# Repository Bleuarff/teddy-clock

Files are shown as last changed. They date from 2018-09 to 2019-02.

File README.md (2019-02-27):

# Teddy-clock

An alarm clock that does not display the time, but lights itself depending on the time of the day.

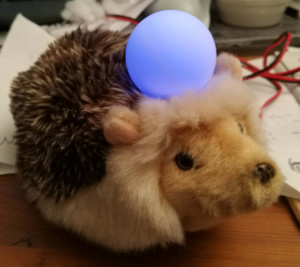
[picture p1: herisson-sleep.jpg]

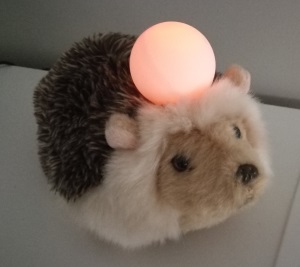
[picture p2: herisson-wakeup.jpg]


## Overview

An esp8266 microcontroller lights an RGB led in different colors depending whether the children must stay in their room or they are allowed to wake their parents up.  
A full-on led in the dead of the night is a sure way for kids to not go back to sleep if they ever wake up. To avoid this, a photoresistor is used to sense ambient light and adjust luminosity accordingly.  
The setup uses an RTC clock with backup battery to help keep time reliably. Daylight saving is taken into account.

The clock uses 3 parameters:
- sleep time: time at which children must go to bed. Led becomes blue,
- wake-up times: times at which children may leve their room at wake their parents up. One for week days, and another one for weekends (one can dream of a Sunday sleep in). Led goes orange for 2 hours.

To update these times, the clock offers a web interface. It's not connected to home wifi for various reasons but instead creates its own SSID when you need it.

## Schema

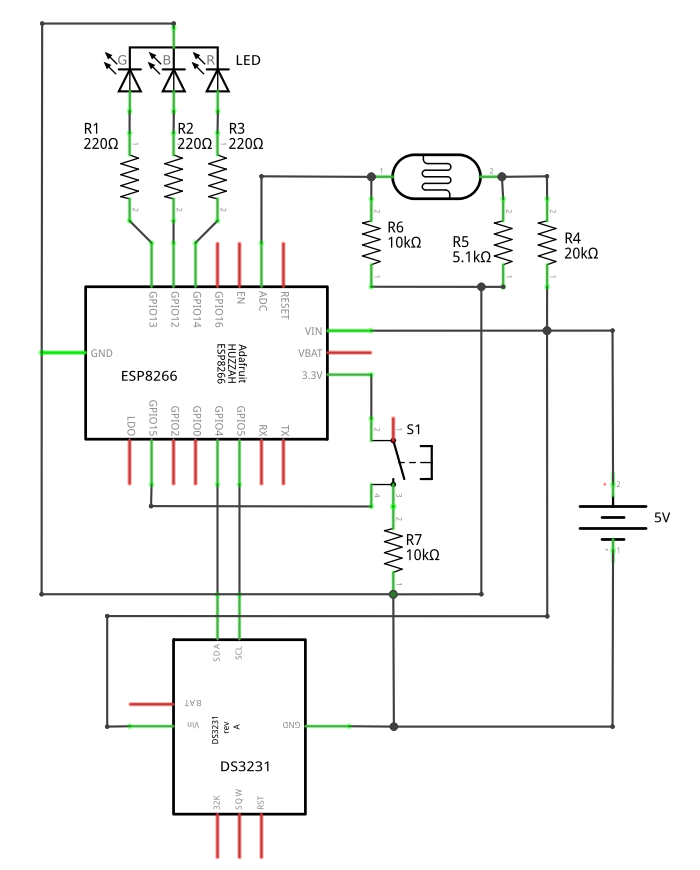
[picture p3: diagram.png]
schema


## Wifi

When you press the button, the clock creates its own SSID. You must connect to network **Hérisson** (public, no authentication). Ease of use trumps everything in such a simple, low-risk project. SSL and auth (WPA2-PSK) are not worth the hassle, both for dev and use. Wifi is off most of the time anyway.  
Go to **http://192.168.14.1** to access the web interface. There, you can edit any of the times (sleep time, wake-up times for weekdays and weekends) as well as the current time and date. Web ui is a single html file uploaded to esp8266's internal file system (SPIFFS).  
The led blinks green when wifi is on. Just press the button again to switch it off.

Why not having it connected permanently?
- home wifi is flaky in the room,
- very sporadic usage does not need 100% connection,
- lower power usage when modem is off

## EEPROM Layout

esp8266 has 4k EEPROM. We use it to store the alarms (4 bytes each) and daylight saving flag (1 if winter time has been done, LSB bit in first byte of the memory bank). Alarm times are stored in minutes since 00:00.

````
Address |  value   | Desc  
--------|----------|------
00h     | 00000001 | winter time change done  
01h-04h |          | sleep time  
05h-08h |          | weekdays wakeup time  
09h-12h |          | weekend wakeup time
````

## Conventions

- Day of week (dow): 1: Monday, 2: Tuesday, (...), 7: Sunday

## Calibration

Light output is proportional to ambiant light. The relation is not the simple identity function f(x) = x.
To create the ideal function, we want to plot values.
The sketch `calibrage` creates a web server (public SSID Hérisson, 192.168.14.1) with endpoints:  
- `GET /sense` to retrieve ambiant light value (theoretically 0-1024),  
- `POST /led?r=R&g=G&b=B` to set led output ; R, G and B being the PWM values for each channel.

We try to find the ideal output in each color (sleep blue and wakeup orange) for multiple ambiant light values. Results are in `resultats_calibrage.ods` file.  
For each channel, we want to write a function that more or less reflects the calibration data points. The ideal function should be superimposed over the data points if plotted along them. We do that by considering that the values between 2 data points should observe an affine function (with data range extremities being minimum & maximum values).  
`tests/pwm_function/pwm_function.cpp` implements the affine functions and compares with calibration data to verify that's ok ; and `herisson/lightModulator.ino` simply copies this code, with a few last-minute adjustments.

## Misc

- DS3231 handles leap years correctly.
- Daylight saving time change is checked and performed on sunday in the last 7 days of march and october. Update time and set winter time flag in eeprom.
- To upload a sketch onto the ESP8266, it must in bootload mode. The procedure is as follow:

    1. Hold down the GPIO0 button, the red LED will be lit
    2. While holding down GPIO0, click the RESET button
    3. Release RESET, then release GPIO0
    4. When you release the RESET button, the red LED will be lit dimly, this means it's ready to bootload

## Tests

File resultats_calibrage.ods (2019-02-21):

Lumière ambiante | Bleu | Red (orange) | Green (orange) | Blue func affine |  | Red affine |  | Green affine
 |  |  |  | coef | y at origin | coef | y at origin | coef | y at origin
0 | 40 | 40 | 80
7 | 40 | 40 | 80
15 | 80
20 | 100 | 70 | 140 |  |  | 2,3076923077 | 23,8461538462 | 4,6153846154 | 47,6923076923
65 | 100 | 100 | 200 |  |  | 0,6666666667 | 56,6666666667 | 1,3333333333 | 113,3333333333
165 | 280 | 200 | 400 | 1,8 | -17 | 1 | 35 | 2 | 70
268 | 400 | 250 | 500 | 1,1650485437 | 87,7669902913 | 0,4854368932 | 119,9029126214 | 0,9708737864 | 239,8058252427
350 | 600 | 350 | 700 | 2,4390243902 | -253,6585365854 | 1,2195121951 | -76,8292682927 | 2,4390243902 | -153,6585365854
416 | 700 | 350 | 700 | 1,5151515152 | 69,696969697 | 0 | 350 | 0 | 700
508 | 800 | 400 | 800 | 1,0869565217 | 247,8260869565 | 0,5434782609 | 123,9130434783 | 1,0869565217 | 247,8260869565
590 | 1000 | 400 | 800 | 2,4390243902 | -439,0243902439 | 0 | 400 | 0 | 800
605 | 1000
700 | 1000 | 500 | 1000 |  |  | 0,9090909091 | -136,3636363636 | 1,8181818182 | -272,7272727273
774 | 1024 | 1024 | 1024 |  |  | 7,0810810811 | -4456,7567567568 | 0,3243243243 | 772,972972973

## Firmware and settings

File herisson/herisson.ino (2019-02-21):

#include <Wire.h>
#include <EEPROM.h>
#include "FS.h"
#include <ESP8266WebServer.h>

const uint8_t RTC_ADDRESS = 0x68; // i2C address of the DS3231

// All possible states for the led
enum LedStates {Dodo, Debout, Off};

const byte redPin = 14;
const byte greenPin = 13;
const byte bluePin = 12;
const byte switchPin = 15;
const int CLOCK_CHECK_INTERVAL = 5000; // time between clock checks

// Object to store timestamp
// seconds are not needed.
struct Time {
  byte hour;
  byte min;
  byte date;
  byte month;
  byte dow;
  byte year;
};

// Store light modulation factor for each rgb channel
// struct ModFactor {
//   float rf; // red channel
//   float gf; // green channel
//   float bf; // blue channel
// };

// 3 alarms needed
int dodo, wakeup1, wakeup2;
bool winterTimeChangeDone;

// timestamp of last time we checked time & set led according to it
unsigned long lastClockCheck;

// server object
ESP8266WebServer server(80);

void setup(){
  Serial.begin(115200);
  Wire.begin();

  pinMode(redPin, OUTPUT);
  pinMode(bluePin, OUTPUT);
  pinMode(greenPin, OUTPUT);
  pinMode(switchPin, INPUT);

  setAirplaneMode();

  // for dev/tests: set RTC
  // setTime((Time){19, 59, 8, 10, 1, 18});

  EEPROM.begin(13); // 13 bytes needed. cf readme for usage/Layout

  winterTimeChangeDone = (EEPROM.read(0) & 0b00000001) == 1;
  Serial.print("Winter time change done: ");
  Serial.println(winterTimeChangeDone ? "oui": "non");

  // get all alarms stored in EEPROM
  EEPROM.get(1, dodo);
  EEPROM.get(5, wakeup1);
  EEPROM.get(9, wakeup2);

  Serial.print("Dodo time: ");
  printAlarm(dodo);
  Serial.print("Lever (semaine): ");
  printAlarm(wakeup1);
  Serial.print("Lever (weekend): ");
  printAlarm(wakeup2);

  if (!SPIFFS.begin()){
    Serial.println("SPIFFS mount fail.");
  }

  lastClockCheck = millis();
}

void loop(){
  static unsigned long lastWifiSwitch = 0;
  static bool isUpdateMode = false; // true when switch is pressed, until next press
  static bool serverOK = false;

  int switchState = digitalRead(switchPin);

  // act upon switch pressed if not too close from last press. Avoids 1 press to be detected multiple times (a kind of debounce)
  if (switchState == HIGH && millis() - lastWifiSwitch >= 3000){
    isUpdateMode = !isUpdateMode;

    if (isUpdateMode){
      // start wifi & server
      serverOK = startServer();
    }
    else{
      // switch off wifi
      bool res = stopServer();
      // led red if error
      if (!res){
        digitalWrite(redPin, HIGH);
        digitalWrite(greenPin, LOW);
        digitalWrite(bluePin, LOW);
        delay(5000);
      }
    }

    lastWifiSwitch = millis(); // debounce: keep track of last time we registered a switch between clock check and update mode
  }

  // in update mode, blink green if wifi & server are set up ok. Otherwise show red
  if (isUpdateMode){
    server.handleClient();
    if (serverOK)
      blink(1);
    else{
      digitalWrite(redPin, HIGH);
      digitalWrite(greenPin, LOW);
      digitalWrite(bluePin, LOW);
    }
  }

  // check time & set led if update mode, (i.e. server) is inactive.
  // also use millis & time compare instead of delay, for non-blocking code
  if (!isUpdateMode && millis() - lastClockCheck >= CLOCK_CHECK_INTERVAL){
    Time t = getTime(); // read time. Already adjusted for daylight savings

    if (t.month == 0){ // in case of error, getTime returns a Time with all members set to 0
      Serial.print("invalid time\n");
      lastClockCheck = millis();
      return;
    }

    printTime(t);

    // gets clock  state to apply
    const LedStates lightState = getLightState(t);
    printState(lightState);

    setLed(lightState); // update led state

    lastClockCheck = millis();
  }
}

// Write RGB values from clockstate
// state: clock state
void setLed(LedStates state){
  int red, green, blue; // pwm value for each pin
  const int lightLvl = analogRead(A0); // ambiant light level

  switch(state){
    case Off:
      red = green = blue = 0;
      break;
    case Dodo:
      red = green = 0;
      blue = (int)computeBlueChannel(lightLvl);
      break;
    case Debout:
      blue = 0;
      green = (int)computeGreenChannel(lightLvl);
      red = (int)computeRedChannel(lightLvl);
      break;
  }
  analogWrite(redPin, red);
  analogWrite(greenPin, green);
  analogWrite(bluePin, blue);

  Serial.printf("A %i\tR %i\tG %i\tB %i\n", lightLvl, red, green, blue);
}

// return the state to apply to the led based on current time & global alarms
// alarms are assumed to be ordered: wakeup1 < wakeup2 < off < dodo
LedStates getLightState(Time t){
  int ts = t.hour * 60 + t.min; // convert time struct into a single number, number of minutes since 00:00
  int wakeup = t.dow <= 5 ? wakeup1 : wakeup2; // sets which wakeup time to use, week or weekend
  int offTime = wakeup + 120; // switch light off 2 hours after wakeup time

  if (ts < wakeup)
    return Dodo;
  else if (ts < offTime)
    return Debout;
  else if (ts < dodo)
    return Off;

  return Dodo;
}

// set modulation factor from light sensor
// Currently: linear relationship between ambiant light value and output led value, for all color channels
// TODO: calibrate: min/max value for min/max ambiant light values. See calibrage_photores sketch
// ModFactor getModFactor(){
//   int lightLvl = analogRead(A0);
//   float lightRatio = (float)lightLvl / 1024;
//   return { lightRatio, lightRatio, lightRatio };
// }

// displays alarm
void printAlarm(int a){
  byte hr = a / 60;
  byte min = a % 60;
  Serial.printf("%i:%i\n", hr, min);
}

void printTime(Time t){
  Serial.print(t.hour);
  Serial.print(":");
  Serial.print(t.min);
  Serial.print(" ");
  Serial.print(t.date);
  Serial.print("/");
  Serial.print(t.month);
  Serial.print(" ");
  Serial.print(t.dow);
  Serial.printf(" 20%i\n", t.year);
}

void printState(LedStates l){
  Serial.print("Apply: ");
  switch (l){
    case Dodo:
      Serial.print("dodo\n");
      break;
    case Debout:
      Serial.print("debout\n");
      break;
    case Off:
      Serial.print("off\n");
      break;
  }
}

// color: specify which color to set when blinking:
// 0: red
// 1: green
// 2: blue
void blink(byte color){
  static unsigned long lastBlink = millis();
  static bool blinkOn = false;

  if (millis() - lastBlink >= 800){
    blinkOn = !blinkOn;

    if (blinkOn){

      digitalWrite(redPin, color == 0 ? HIGH : LOW);
      digitalWrite(greenPin, color == 1 ? HIGH : LOW);
      digitalWrite(bluePin, color == 2 ? HIGH : LOW);
    }
    else{
      digitalWrite(redPin, LOW);
      digitalWrite(greenPin, LOW);
      digitalWrite(bluePin, LOW);
    }

    lastBlink = millis();
  }
}

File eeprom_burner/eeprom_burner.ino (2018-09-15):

// Send file data, write each byte to eeprom, starting at offset 2.
// when file complete, get length and write to eeprom at offset 0. Then proceeds to read the content and send it back

// uses an RGB led for debugging. Blue: arduino started. Red: message incoming. Green: message finished

#include <Wire.h>
#define EEPROM_ADDRESS 0x50 // i2C address of the 24LC256 eeprom
#define BUFFER_SIZE 30 // Wire internal buffer is 32 bytes, of which 2 are for the address
#define PAGE_SIZE 64 // EEPROM page size

unsigned int numReceived = 0; // counter of bytes received
boolean newData = false;

void setup(){
  Serial.begin(9600); // slower baud rate to ease pressure on code execution time
  Wire.begin();

  // set led pins
  pinMode(6, OUTPUT);
  pinMode(3, OUTPUT);
  pinMode(5, OUTPUT);

  setLed(0,0,255);

  delay(100);
  i2cReady(0x50);
}

void loop(){
  receive();
  show();
}

void receive(){
  static boolean recvInProgress = false;
  static int ndx = 0;

  // start and end marker around message
  byte startMarker = 0x02;
  byte endMarker = 0x03;
  byte rb;

  while (Serial.available() > 0 && newData == false){
    rb = Serial.read();

    if (recvInProgress == true){
      if (rb != endMarker){
        ndx++;
        // store byte in buffer
        Wire.write(rb);

        // Serial.print(rb);
        // Serial.print(" ");

        // stop and send data when either Wire buffer limit is reached or to not cross page boundaries on the 24LC256
        if ((ndx % BUFFER_SIZE == 0) || ((ndx+2) % PAGE_SIZE == 0)){
          Wire.endTransmission();
          byte hob = ((ndx + 2) & 0xff00) >> 8;
          byte lob = (ndx + 2) & 0x00ff;

          // Serial.print("\nwrite page - new page address: ");
          // Serial.print(hob);
          // Serial.print("/");
          // Serial.println(lob);

          i2cReady(EEPROM_ADDRESS);

          // open connection for next page
          Wire.beginTransmission(EEPROM_ADDRESS);
          Wire.write(hob);
          Wire.write(lob);
        }
      }
      else{
        Serial.println("\nMessage end");
        recvInProgress = false;
        numReceived = ndx;
        ndx = 0;
        newData = true;
        setLed(0, 255,0);
        Wire.endTransmission();
        writeContentLength(numReceived);
      }
    }
    else if (rb == startMarker){
      Serial.println("Message start");
      recvInProgress = true;
      setLed(255,0,0);

      // open connection to memory chip and set address
      Wire.beginTransmission(EEPROM_ADDRESS);
      Wire.write(0);
      Wire.write(2);
    }
  }
}

void writeContentLength(int length){
  // split length int into 2 bytes
  byte lob = length & 0x00ff;
  byte hob = (length & 0xff00) >> 8;

  Serial.print("Write content length: ");
  Serial.print(length);
  Serial.print("  ");
  Serial.print(hob);
  Serial.print("/");
  Serial.println(lob);

  i2cReady(EEPROM_ADDRESS);
  Wire.beginTransmission(EEPROM_ADDRESS);
  Wire.write(0);
  Wire.write(0);

  // write length bytes
  Wire.write(hob);
  Wire.write(lob);
  Wire.endTransmission();
}

void show(){
  if (newData == true){
    Serial.print("data in...");
    Serial.print(numReceived);
    Serial.println(" bytes received");
    newData = false;

    readContent(numReceived + 3);
  }
}

void readContent(int length){
  Serial.println("\nMemory dump:");
  int pages = length / 32 + 1;

  bool ready = i2cReady(EEPROM_ADDRESS);

  // Set pointer at 0 and let it roll, no need to set it after that.
  Wire.beginTransmission(EEPROM_ADDRESS);
  Wire.write(0);
  Wire.write(0);
  Wire.endTransmission();
  i2cReady(EEPROM_ADDRESS);

  for(int i = 0; i < pages; i++){
    int address = i * 32;

    int readLength = (i < pages - 1) ? 32 : length % 32;
    // Serial.print("read length ");
    // Serial.println(readLength);


    Wire.requestFrom(EEPROM_ADDRESS, readLength);
    while(Wire.available()){
      byte b = Wire.read();
      Serial.print(b);
      Serial.print(" ");
    }

    Serial.println();
  }
  Serial.print("\n\n\n\n\n");

}

void setLed(int red, int green, int blue){
  analogWrite(6, red);
  analogWrite(3, green);
  analogWrite(5, blue);
}

bool i2cReady(uint8_t adr){
  uint32_t timeout = millis();
  bool ready = false;
  while((millis() - timeout < 100) && (!ready)){
    Wire.beginTransmission(adr);
    int err = Wire.endTransmission();
    ready = (err == 0);
  }
  if (ready == false)
    Serial.println("Not ready !");
  // Serial.print("ready: ");
  // Serial.println(ready);
  return ready;
}

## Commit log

2018-04-04 New file ledclock: switch on/off leds based on command line argumentwq
2018-04-07 Schematics.
    + remove unneeded files
2018-06-08 starts work on V2!
    includes: parts list, fritzing schematics, and a spike to dim led based on light around.
    [composants.ods, overview_V2.fzz]
2018-06-23 Some spikes to test RTC usage & time changes. README: map arduino EEPROM usage layout for reference.
2018-06-27 Refactor alarm internal representation
    Alarm is stored as int, number of minutes since start of day.
    + method to determine which state to apply to LED, based on current time and alarms
2018-06-29 - Write rgb values to led - refactor for light modulation factor
2018-07-10 Linear relationship between ambiant light and led output.
    To be updated based on tests.
2018-07-10 Set led output values based on ambiant light value.
    Current: very simple (linear) function.
2018-09-02 Upload data through serial
    arduino part uses led to show message state:
    - blue: arduino started, no message received
    - green: message being received
    - red: message ended
2018-09-13 Fix write issues on memory: do not write across page boundaries
    + include test sketches
    [eeprom_burner.ino, filewrite.ino, read_external_memory.ino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]
2018-09-13 Small fixes on file upload:
    - message size counter should be an int, not a byte
    - reduce wait time between pages sent by upload script
    - remove debugging messages
    [eeprom_burner.ino, uploadFile.js]
2018-09-15 Fix eeprom burner sketch
    No need to manually set address pointer for each page
    [eeprom_burner.ino]
2018-09-16 Arduino sketch that does nothing
2018-09-16 tests/spikes: led blink, eeprom reading with esp8266
2018-09-23 Managed to serve file from ESP \o/
    - reading eeprom is a failure (wdt reset, various exceptions)
    - ESP has a file system (1Mb) ! store file there (arduino IDE plugin to upload files)
    - use SPIFFS library to access file system
    esp_fs_info: test fs
    esp_serve_file: test server that delivers file from FS
    [esp_fs_info.ino, esp_read_eeprom.ino, esp_serve_file.ino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]
2018-09-25 Start work to move everything on the esp8266 !!
    herisson: main sketch - all logic. currently only EEPROM reading from alarms and time checking with DS3231 (inc. dst)
    tests: test sketches with PWM led and EEPROM read/write (there's some difference with base arduino's eeprom)
    webui: cosmetic changes
2018-09-26 Move arduino-specific to a dedicated folder
2018-09-26 Get to feature parity on esp as was on arduino nano ! - plugged photoresistor and rgb led
    esp_analog_red: test how to read from analog input on esp
2018-09-29 Add switch to go into update mode (and back again)
2018-09-29 update fritzing object to last version of circuit:
    - remove arduino, 24LC25
    - add resistor voltage divider for photoresistor
    [overview_V2.fzz]
2018-09-30 start/stop wifi on switch press
    + with led status on state change.
    TODO: investigate sleep modes.
2018-10-03 update fritzing view to latest version of circuit
    [overview_V2.fzz]
2018-10-03 set up web server with basic bindings
    - serve html file from spiffs
    - basic binding
    - ignore data folder in sketch, contains a symbolic link to webui.html
    [esp_serve_file.ino, herisson.ino, server.ino]
2018-10-06 /alarms POST endpoint to set all 3 alarms
    -receive value & convert to int OK
    - bug trying to save to EEPROM. After a reset/power cycle, old value is still there.
    [herisson.ino, server.ino]
2018-10-10 - fix timing bug if invalid time is read: respect the 5s interval - error checking in set time endpoint
    [herisson.ino, server.ino]
2018-10-14 UI: retrieve current time, controls to edit it.
    + refactor style
2018-10-16 Change GPIO to read switch press, use 15.
    There's a pull-down, so no risk of triggering boot-mode on reset.
    [herisson.ino]
2018-10-17 fixbug: commit EEPROM changes when changing winter time change flag
    + set time endpoint returns the current time instead of a 204
    [ds3231.ino, server.ino]
2018-11-07 Update fritzing model. Only the PCB view is complete/accurate.
    [Herisson v2.fzz, overview_V2.fzz]
2018-11-12 box stl model files, doc
    [Boitier_sketchup.stl]
2018-11-14 Remove old uneeded files
    [composants.ods]
2018-11-26 reinforce model with support for all walls
    [Boitier_sketchup.stl]
2019-01-22 Add calibration script (first draft)
    creates web server with 2 endpoints:
    - return light level
    - set led to given rgb value
2019-01-23 Fix calibration sketch
2019-01-23 Fix PWM values. ESP8266's PWM range is 0-1023, not 0-255 like on arduino.
    [herisson.ino]
2019-02-11 Draft doc about calibration process.
2019-02-17 Refactor PWM modulation
    Use a dedicated function for each RGBV channel instead of a simple factor.
    Function stubs are in new file lightModulator.ino.
    Add libreoffice calc file resultats_calibrage.ods that contains all data points tested during calibration.
    Also, light doc edit.
    [resultats_calibrage.ods]
2019-02-20 New program to test pwm modulation functions calc file to find out these functions
    [resultats_calibrage.ods]
2019-02-21 Update herisson with pwm modulation functions for each RGB channel
    - implement & verify modulation function for green channel (compare with calibration data)
    - copy code from test to herisson sketch
    - calibration data (ods file): style, presentation
    [resultats_calibrage.ods]
2019-02-21 Update doc on calibration process.
2019-02-25 Add picture of finished device
2019-02-27 Fix lowest PWM values, doc.
    [lightModulator.ino]
2020-04-08 New sketch to set default values
    Writes default settings in EEPROM before using the board.
